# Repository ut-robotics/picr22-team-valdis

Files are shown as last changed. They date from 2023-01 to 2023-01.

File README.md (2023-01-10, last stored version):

# picr22-team-valdis

Pinout for STM32G441KBT6

PA0 - M1_PWM_A

PA1 - M2_PWM_A

PA2 - M3_PWM_A

PA3 - TRW_PWM

PA5 - M1_DIR_A

PA6 - M2_DIR_A

PA7 - M3_DIR_A

PA8 - M1_ENC_A

PA9 - M1_ENC_B

PA11 - USB_N

PA12 - USB_P

PA13 - SWDIO

PA14 - SWCLK

PF0-OSC_IN - LED

PG10-NRST - NRST

PB3 - SLEEP_n

PB4 - M2_ENC_A

PB5 - M2_ENC_B

PB6 - M3_ENC_B

PB7 - M3_ENC_A

Pins 1,17,15,16,32,14 are used for power. Rest of unmentioned pins were not used

For motor encoder inputs we used 2 channel inputs for each motor. Depicted as ENC_A and ENC_B connections. 
For output we used PWM and DIR (direction) where PWM transmitted speed and DIR chose which way the wheel spun.
The thrower was initially planned to use D-SHOT but due to time limitations we used simple PWM output.
Sleep_n is used to wake up motors.

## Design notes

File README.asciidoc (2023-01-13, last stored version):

# picr22-team-valdis Motor and Mainboard drivers

The purpose of this board is to control 3 motor drivers and 1 additional servo. This can be done with an external serial connection through USB. Additionally, the board also provides power for the 3 motor drivers (servo requires separate power source).

The main communication for each motor goes through STM32G441KBT6, which is separately programmable through J2 connector. Power delivery for this chip is supplied via USB 5V which is converted down to 3.3V through a voltage regulator (NCP164CSN330T1G). The USB connection also has protection provided by CM1223-02SO TVS diode package. An additional debug LED is also connected to indicate if signal is being outputted to motor drivers.

The motor driver side is powered by an external LiPo battery (in our case a 16.8V 4S) and is isolated from the MCU side. Before the signal reaches motor drivers, it goes through isolators (MAX14930DASE+) to ensure correct signal between two board power supplies. Batteries are connected via 4x4mm solder pads and go through a reverse voltage protector (BUK6Y10-30P) to protect components. For providing power to the isolators, voltage is dropped from 16V to 5V via voltage regulator (NCV8730ASN500T1G).

Motor drivers (PDRV8243HRXYQ1) receive 16.8V input for power. From the isolators, drivers receive a PWM, direction and sleep signal. PWM signal tells how fast the motors have to spin and direction signal indicates via boolean (0 or 1) which way the wheel spins. Sleep signal is basically there to wake up the motor drivers from standby state. For simplicity we connected DRVOFF to ground, which means that they will never be turned off while power is connected. Current for motor drivers are limited with 47K resistors through ITRIP pin and 2.2K resistors through IPROP pin. This sets ITRIP voltage to 2.31V and driver output current to around 3.2A. Motor driver power is also supplied through 4x4mm solder pads.

== Pinout for STM32G441KBT6

PA0 - M1_PWM_A (wheel PWM signal output)

PA1 - M2_PWM_A (wheel PWM signal output)

PA2 - M3_PWM_A	(wheel PWM signal output)

PA3 - TRW_PWM (thrower PWM signal)

PA5 - M1_DIR_A	(wheel direction output)

PA6 - M2_DIR_A (wheel direction output)

PA7 - M3_DIR_A (wheel direction output)

PA8 - M1_ENC_A (wheel encoder read)

PA9 - M1_ENC_B (wheel encoder read)

PA11 - USB_N (USB input data-)

PA12 - USB_P (USB input data+)

PA13 - SWDIO (Serial Wire Data I/O)

PA14 - SWCLK (Serial Wire Clock)

PF0-OSC_IN - LED (debug led for sending commands)

PG10-NRST - NRST (MCU reset)

PB3 - SLEEP_n (signal to wake up motor driver)

PB4 - M2_ENC_A (wheel encoder read)

PB5 - M2_ENC_B (wheel encoder read)

PB6 - M3_ENC_B (wheel encoder read)

PB7 - M3_ENC_A (wheel encoder read)

Pins 1,17,15,16,32,14 are used for power. Rest of unmentioned pins were not used.

== J2 Programmer

1 - 3.3V

2 - SWDIO

3 - GND

4 - SWCLK

5 - GND

6 - NC

7 - NC

8 - NC

9 - GND

10 - NRST

== J3 Motor 1

1 - GND

2 - 3.3V

3 - M1_ENC_A

4 - M1_ENC_B

== J4 Motor 2

1 - GND

2 - 3.3V

3 - M2_ENC_A

4 - M2_ENC_B

== J5 Motor 3

1 - GND

2 - 3.3V

3 - M3_ENC_A

4 - M3_ENC_B

== J6 Thrower 

1 - GND

2 - TRW_PWM

3 - NC

4 - NC

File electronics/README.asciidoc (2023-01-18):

# picr22-team-valdis Motor and Mainboard drivers

The purpose of this board is to control 3 motor drivers and 1 additional servo. This can be done with an external serial connection through USB. Additionally, the board also provides power for the 3 motor drivers (servo requires separate power source).

The main communication for each motor goes through STM32G441KBT6, which is separately programmable through J2 connector. Power delivery for this chip is supplied via USB 5V which is converted down to 3.3V through a voltage regulator (NCP164CSN330T1G). The USB connection also has protection provided by CM1223-02SO TVS diode package. An additional debug LED is also connected to indicate if signal is being outputted to motor drivers.

The motor driver side is powered by an external LiPo battery (in our case a 16.8V 4S) and is isolated from the MCU side. Before the signal reaches motor drivers, it goes through isolators (MAX14930DASE+) to ensure correct signal between two board power supplies. Batteries are connected via 4x4mm solder pads and go through a reverse voltage protector (BUK6Y10-30P) to protect components. For providing power to the isolators, voltage is dropped from 16V to 5V via voltage regulator (NCV8730ASN500T1G).

Motor drivers (PDRV8243HRXYQ1) receive 16.8V input for power. From the isolators, drivers receive a PWM, direction and sleep signal. PWM signal tells how fast the motors have to spin and direction signal indicates via boolean (0 or 1) which way the wheel spins. Sleep signal is basically there to wake up the motor drivers from standby state. For simplicity we connected DRVOFF to ground, which means that they will never be turned off while power is connected. Current for motor drivers are limited with 47K resistors through ITRIP pin and 2.2K resistors through IPROP pin. This sets ITRIP voltage to 2.31V and driver output current to around 3.2A. Motor driver power is also supplied through 4x4mm solder pads.

This board should be fine to operate any brushed 12V DC motor with a power output that exceeds 3.2A. For our general purpose we used 12V Pololu motors with a stall current of 5.5A at 12V. It is also important to use motors with encoders, otherwise the firmware won't work properly.

== Pinout for STM32G441KBT6

PA0 - M1_PWM_A (wheel PWM signal output)

PA1 - M2_PWM_A (wheel PWM signal output)

PA2 - M3_PWM_A	(wheel PWM signal output)

PA3 - TRW_PWM (thrower PWM signal)

PA5 - M1_DIR_A	(wheel direction output)

PA6 - M2_DIR_A (wheel direction output)

PA7 - M3_DIR_A (wheel direction output)

PA8 - M1_ENC_A (wheel encoder read)

PA9 - M1_ENC_B (wheel encoder read)

PA11 - USB_N (USB input data-)

PA12 - USB_P (USB input data+)

PA13 - SWDIO (Serial Wire Data I/O)

PA14 - SWCLK (Serial Wire Clock)

PF0-OSC_IN - LED (debug led for sending commands)

PG10-NRST - NRST (MCU reset)

PB3 - SLEEP_n (signal to wake up motor driver)

PB4 - M2_ENC_A (wheel encoder read)

PB5 - M2_ENC_B (wheel encoder read)

PB6 - M3_ENC_B (wheel encoder read)

PB7 - M3_ENC_A (wheel encoder read)

Pins 1,17,15,16,32,14 are used for power. Rest of unmentioned pins were not used.

== J2 Programmer

1 - 3.3V

2 - SWDIO

3 - GND

4 - SWCLK

5 - GND

6 - NC

7 - NC

8 - NC

9 - GND

10 - NRST

== J3 Motor 1

1 - GND

2 - 3.3V

3 - M1_ENC_A

4 - M1_ENC_B

== J4 Motor 2

1 - GND

2 - 3.3V

3 - M2_ENC_A

4 - M2_ENC_B

== J5 Motor 3

1 - GND

2 - 3.3V

3 - M3_ENC_A

4 - M3_ENC_B

== J6 Thrower 

1 - GND

2 - TRW_PWM

3 - NC

4 - NC

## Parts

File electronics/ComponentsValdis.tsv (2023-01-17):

Mainboard
Name | Description | Designator | Quantity | Mouser order code | Farnell order code | TME order code
STM32G441KBT6 | Microcontroller, 32-pin | U2 | 1 | 511-STM32G441KBT6 | 3132413 | -
10118193-0001LF | Micro USB socket | J1 | 1 | 649-10118193-0001LF | 2751675 | 10118193-0001LF/C
CM1223-02SO | TVS diodes 2-channel | U1 | 1 | 748-CM1223-02SO | 3607672 | CM1223-02SO
BUK6Y10-30PX | PFET SOT669 | Q1 | 1 | 771-BUK6Y10-30PX | 3438512 | BUK6Y10-30PX
MAX14930DASE+ | 4-channel isolator | U3,U4 | 2 | 700-MAX14930DASE+ | 3257451 | -
FTSH-105-01-L-DV-K | Programmer connector | J2 | 1 | 200-FTSH10501LDVK | 3550960 | -
NCV8730ASN500T1G | LDO 5V 150mA | U5 | 1 | 863-NCV8730ASN500T1G | 3463974 | -
NCP164CSN330T1G | LDO 3.3V 300mA | U6 | 1 | 863-NCP164CSN330T1G | 3367831 | NCP164CSN330T1G
Micro-MaTch 215079-4 | 4-pin connector | J3-J6 | 4 | 571-215079-4 | 1772996 | AMP-7-215079-4
Capacitor 100 nF | package 0603 | C2-C9 | 8 | 581-06035C104KAT2A | 1740614 | 0603B104J500CT
Capacitor 1 uF | package 0603 | C10-C13 | 4 | 581-06035C105KAT2A | 2118128 | 06033D105KAT2A
Capacitor 4.7 uF | package 0603 | C1 | 1 | 963-JMK107BB7475KA-T | 3013398 | GRJ188C70J475KE11D
Resistor 3K3 Ohm | package 0603 | R1-R5 | 5 | 603-RC0603FR-103K3L | 9238549 | WF06P-3K3-5%
LED | white 0603 | D1-D5 | 5 | 593-LSM0603443V | 1716769 | FYLS-0603UWC
Motor Driver
Name | Description | Designator | Quantity | Mouser order code | Farnell order code | TME order code
PDRV8243HRXYQ1 | Motor driver | U7,U8,U9 | 3 | 595-DRV8243HQRXYRQ1 | - | -
Capacitor 10 uF | package 0805 | C14-C17, C20-C23, C26-C29 | 12 | 581-08053D106KAT4A | 2346927 | C2012X5R1E106KAB
Capacitor 100 nF | package 0603 | C18,C19,C24,C25,C30,C31 | 6 | 581-06035C104KAT2A | 1740614 | 0603B104J500CT
Resistor 47K Ohm | package 0603 | R8,R14,R20 | 3 | 279-CRGCQ0603J47K | 2908376 | RC0603FR-0747K
Resistor 2K2 Ohm | package 0603 | R11,R17,R23 | 3 | 279-CRGCQ0603F2K2 | 9233423 | RC0603JR-072K2
Resistor 0 Ohm | package 0603 | R7,R9,R10,R13,R15,R16,R19,R21,R22 | 9 | 652-CR0603-J/-000ELF | 9233130 | RC0603JR-070R
LED | white 0603 | D6,D7,D8 | 3 | 593-LSM0603443V | 1716769 | FYLS-0603UWC
Resistor 3K3 Ohm | package 0603 | R6,R12,R18 | 3 | 603-RC0603FR-103K3L | 9238549 | WF06P-3K3-5%

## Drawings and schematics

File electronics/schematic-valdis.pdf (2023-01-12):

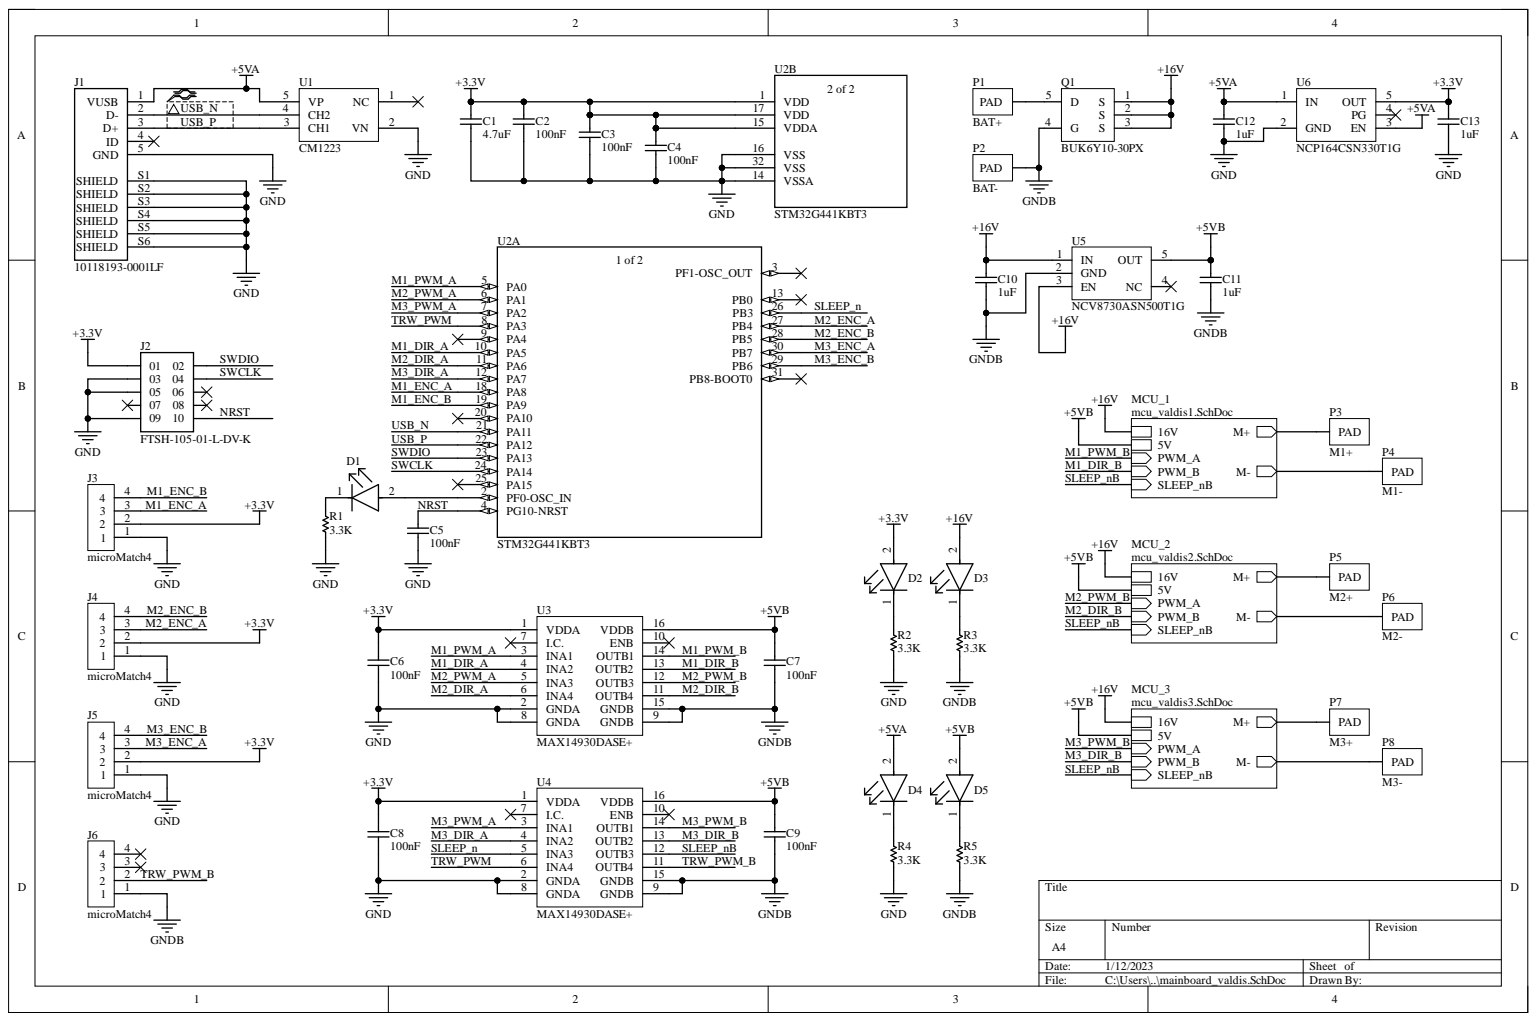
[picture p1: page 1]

1 | | 1 4 M1 _PWM_

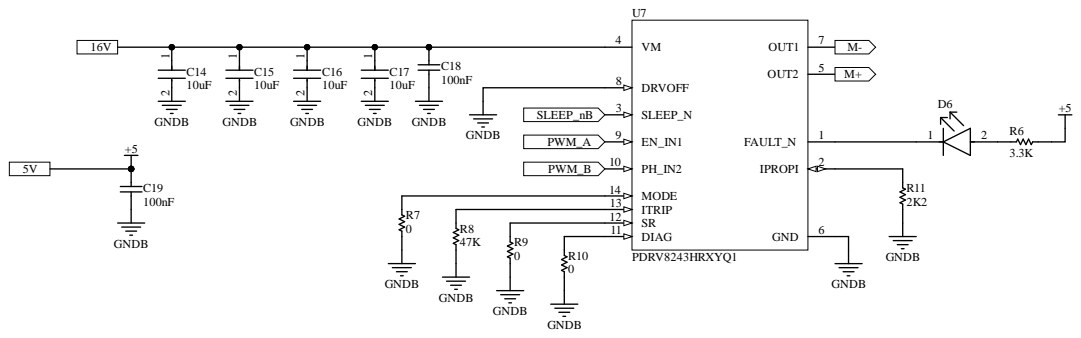
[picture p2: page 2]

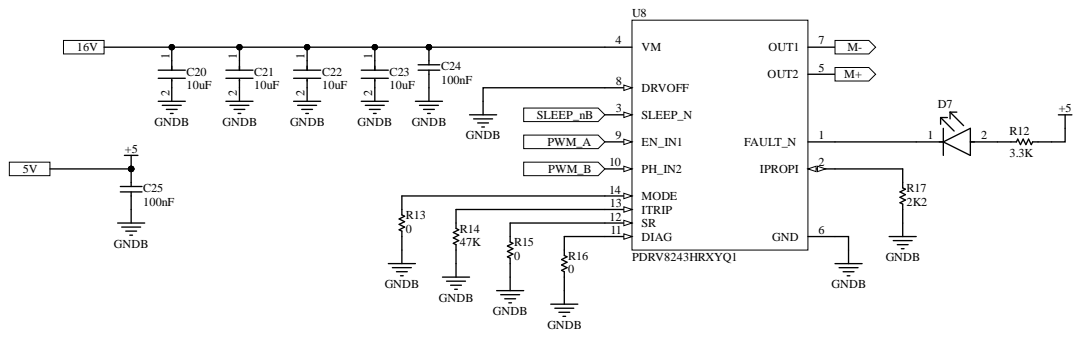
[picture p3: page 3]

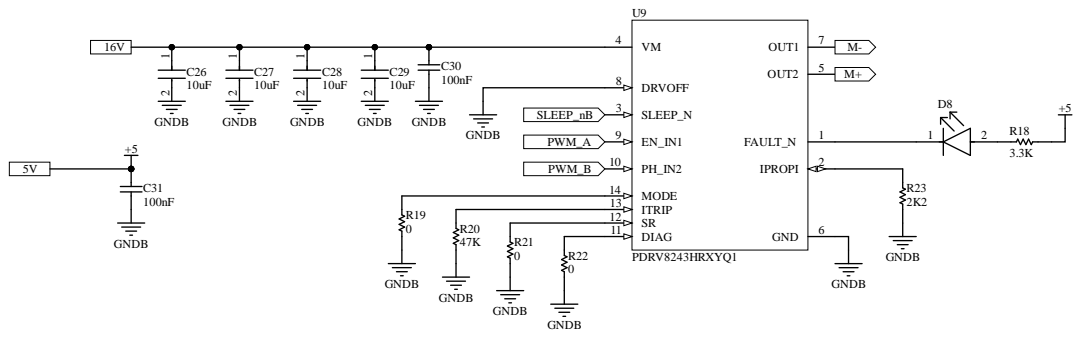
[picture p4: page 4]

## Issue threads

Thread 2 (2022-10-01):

[Mechanics] attach thrower assembly to chassis

Akustav, 2022-10-01:
I did not find a assembly file where the chassis and thrower are combined. Such a file allows to validate that the thrower will work in the chassis.

vircoh, 2022-10-02:
Asub Chassis kaustas: Robot throweritega

Closed 2022-10-05.

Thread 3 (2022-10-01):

[Mechanics] blue lines in sketches

Akustav, 2022-10-01:
Some sketches are left under defined. This can make it difficult to modify components later on and can create unpredictable situations when modifying things. This can be fixed by adding measurements to sketches until every line is black.

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

vircoh, 2022-10-02:
Võiks olla korras

Akustav, 2022-10-05:
Am I looking at the correct file? wall3 v15 has a lot of blue:
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

Ramp3 v4 has one hole underdefined:
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

Closed 2022-11-05.

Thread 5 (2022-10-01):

[Mechanics] mounting hole size too large

Akustav, 2022-10-01:
Mounting holes for the thrower should have 2.5mm holes that can be threaded and used with M3 bolts.
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

vircoh, 2022-10-02:
done - 2.5mm

Closed 2022-10-05.

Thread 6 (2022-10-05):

[Mechanics] thrower motor seems to be too low

Akustav, 2022-10-05:
The motor is currently too low. It should compress the ball a few mm, like 2-3 mm. Currently it is 7.8mm

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

Also add the motor to the assembly. It does not need to be too detailed, a cylinder with mounting holes and a rectangle representing the power cables is enough.

Closed 2022-11-05.

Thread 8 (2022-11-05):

[Mechanics] errors is assembly

Akustav, 2022-11-05:
Thr omniwheel assembly seems to have warnings:

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

vinku34, 2022-11-05:
Fixed errors in timeline

Closed 2022-11-26.

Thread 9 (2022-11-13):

MCU pin assignment

ReikoR, 2022-11-13:
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

USB and programmer pins must be connected to pins PA11 to PA14:
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

Most of the other pins also would not work.

Try to use STM32CubeIDE for creating the pin assignment.

Some more information on how to configure timers in STM32CubeIDE is on the firmware page:
https://ut-robotics.github.io/picr22-home/basketball_robot_guide/electronics/firmware.html

Please ask if it's not clear how to do the timer configuration and pin assignment.

ReikoR, 2022-11-16:
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

Pin assignment is ok, but why are you naming all the signals `ENC`?

Something like this would be more understandable:
* `M1_PWM` - Motor 1 PWM
* `M1_DIR` - Motor 1 direction
* `M1_ENC_A` - Motor 1 encoder A
* `M1_ENC_A` - Motor 2 encoder B
* `TRW_PWM` - Thrower PWM

ReikoR, 2022-11-18:
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

Each driver has one PWM and one direction input.

Connections should look like this:
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

ReikoR, 2022-11-19:
It would make the firmware a bit simpler if all ENC_A signals where connected to timer channel 1.

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

Closed 2022-11-20.

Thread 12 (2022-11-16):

+3.3V power port not connected

ReikoR, 2022-11-16:
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

ReikoR, 2022-11-18:
Now it's missing:
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

Closed 2022-11-19.

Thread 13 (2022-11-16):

Thrower PWM signal should go through isolator

ReikoR, 2022-11-16:
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

`DRVOFF` can be removed from MCU and connected to `GNDB` on motor drivers. Then an additional isolator is not needed.

I don't think there is any need to turn off drivers from MCU.

Closed 2022-11-18.

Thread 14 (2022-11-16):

Don't use metric grid on the schematic

ReikoR, 2022-11-16:
Industry standard unfortunately is 100 mil grid. All the symbols are designed for it. Using different grid can cause issues with things not aligning with each other.

On the PCB it's better to use metric grid.

Closed 2022-11-18.

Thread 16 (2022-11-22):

Incorrect MicroMatch footprint

ReikoR, 2022-11-22:
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

From the [drawing](https://www.te.com/commerce/DocumentDelivery/DDEController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):
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

Polarization hole is too small:
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

Also pin numbering should start from the polarization hole side.

You can use this library:
https://github.com/ReikoR/altium-custom-libraries/tree/master/connectors_micromatch

Or some other library, if you find a correct one.

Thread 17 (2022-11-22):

NCV8730ASN500T1G footprint incorrect

ReikoR, 2022-11-22:
Pin pitch on the footprint is 0.65 mm:
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

Correct from [datasheet ](https://www.onsemi.com/pdf/datasheet/ncv8730-d.pdf) is 0.95 mm:
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

ReikoR, 2022-12-02:
Still incorrect:
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

Closed 2022-12-04.

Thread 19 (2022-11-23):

Route USB data signals as differential pair

ReikoR, 2022-11-23:
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

For more info:
https://github.com/ut-robotics/picr22-team-gibibot/issues/32

But use JLC7628 stackup instead of JLC3313 as it is cheaper.

USB differential pair trace width and spacing is different for JLC7628 stackup.

For example 8 mil (about 0.2 mm) trace space and 10.28 mil (about 0.26 mm) trace width would work:
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

ReikoR, 2022-11-27:
1. JLC7628 stackup not being used:
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

2. Avoid creating stubs. Stubs create reflections.
\
Current layout:
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
\
Proposed layout:
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

ReikoR, 2022-12-02:
JLC7628 stackup still not being used. Track width needs to be changed.

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

Closed 2022-12-04.

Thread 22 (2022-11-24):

[Mechanics] CAM issues

maidlam, 2022-11-24:
Arrange:
Set "Object Spacing" to 7 mm. The space between the parts should be greater than 6 mm, because the tool is 3 mm in diameter, the toolpath will want to preserve the stock between parts until the end, causing longer milling time.

2D Pocket:

- Change Stock to Leave > Axial Stock to Leave to 0
- Disable Lead-In and Lead-Out
- Change Ramp > Ramp type to Plunge

2D Contour1 (hole for the motor shaft)

- Enable tabs, set "Tab height" to 0,3 mm, set "Tab distance" so that it generates two tabs for the inner piece
- Enable Multiple Depths and set the "Maximum Roughing Stepdown" to 1 mm
- Enable Stock to Leave, set Radial Stock to leave to -0,05 - this will let the shaft brim fit more easily, by making the hole a little bit bigger.
- Disable Lead-In and Lead-Out

2D Contour2 (outside contours)

- Change "Tab height" to 0,3 mm
- Enable Multiple Depths and set the "Maximum Roughing Stepdown" to 1 mm
- Disable Lead-In and Lead-Out

Closed 2022-11-27.

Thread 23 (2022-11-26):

Not that many mounting points needed

Akustav, 2022-11-26:
I suggest not to use these mounting holes because they add more complexity for barely any benefit. same for the bottom holes:

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

vinku34, 2022-11-26:
Removed ramp mounting holes on top and bottom plate

Closed 2022-12-04.

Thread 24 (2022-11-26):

Consider using mountable XT-60 sockets

Akustav, 2022-11-26:
Maybe the use of a mountable XT-60 socket like this is good to power the robot.
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

vinku34, 2022-11-26:
do we have this kind of mountable connector or would I have to make a holder to make it mountable?

Akustav, 2022-12-04:
They are available in the lab

vinku34, 2022-12-05:
I made a variant with these mountable sockets. The current issue would be on the side with the NUC power cable. Right now I can move it closer to the edge a bit but im not 100% sure if it will clear the power cable or not.
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

Also the holes in the rear acted as a place to shove the battery voltage displays. I have an Idea to mount them here with 3D printed boxes and screw in from the inside with the same flush fit as most of the bolts I have. with little indents for nuts so that I dont have to thread plastic
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

Akustav, 2022-12-07:
Seems reasonable. Also FYI, the XT-60 sockets themselves have threaded inserts, so you just need a 3mm hole to mount them. Your current holes are 2.5mm

Closed 2022-12-14.

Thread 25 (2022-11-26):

How do sidewalls mount

Akustav, 2022-11-26:
What fastening stiles is used for the sidewalls? Currently they look bottom mounted. What holds them in place?

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

vinku34, 2022-11-26:
Bolts go through from the bottom and thread into a nyloc nut from the top.

Akustav, 2022-12-04:
Hm okay. I guess

Closed 2022-12-04.

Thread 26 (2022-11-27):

Add grounds to both internal layers

ReikoR, 2022-11-27:
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

Add `GND` net polygon on both internal layers on the MCU side and `GND_M` net polygon on both layers on the motor drivers side.

Grounds are reference planes for signal and power connections on outer layers and having reference plane close to signals improves signal integrity.

ReikoR, 2022-12-02:
There are duplicate polygons. I moved them for the picture.
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

Closed 2022-12-04.

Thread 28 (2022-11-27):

Fix DRC errors

ReikoR, 2022-11-27:
There are unrouted nets and other problems.

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

ReikoR, 2022-12-02:
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

Some of the solder mask sliver errors can be fixed by adding back general Solder Mask Expansion rule and setting expansion to 0.05mm (JLCPCB minimum).
From https://jlcpcb.com/capabilities/Capabilities
> Solder mask opening/ expansion 0.05mm

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

Via Solder Mask Expansion rule should be the first one. Rule order can be changed with _Priorities..._ button.

Correct minimum solder mask sliver should be 0.254 mm, which will cause more errors.

From https://jlcpcb.com/capabilities/Capabilities
> Solder bridge: 0.2mm(green), 0.254mm(other colors)

PCBs will be black.

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

It should be ok to ignore solder mask sliver errors that can't be fixed.

Closed 2022-12-04.

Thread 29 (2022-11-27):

Avoid routing over gaps

ReikoR, 2022-11-27:
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

If If there is not a solid ground on the adjacent layer, then the return current has to flow in a bigger loop, which causes more noise.

Closed 2022-12-02.

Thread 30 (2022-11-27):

Place decoupling capacitors on the same layer as the components

ReikoR, 2022-11-27:
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

Placing capacitors on the same layer close to the power pins makes the connection shorter, which reduces inductance.

Closed 2022-12-02.

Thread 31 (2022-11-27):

Use wider tracks or polygons and multiple vias for higher currents

ReikoR, 2022-11-27:
1. High current connections are quite narrow.
\
Current layout:
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
\
0.254mm wide copper can carry about 1.7 A of current at 20 degrees temperature rise:
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
\
For 3 A, the temperature needs to rise by 73 degrees.
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

2. Multiple smaller vias instead of fewer larger vias is usually better as smaller vias can carry more current per area.
\
Current layout:
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
\
0.2/0.45mm via:
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
\
0.6/1mm vias:
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

More copper and better connection to it also helps with thermal performance.

ReikoR, 2022-12-02:
1. More vias should be added to +16V from MOSFET.
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

2. Motor driver capacitors would be more effective if they were closer to motor drivers. Smallest (100nF) capacitor should be the closest. Shorter connections have lower inductance.
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

3. There are 2 overlapping +16V polygons.
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

4. Improve `SLEEP_nB` routing so that it does not cut into +16V polygon.
\
Current layout:
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
\
Proposed layout (routed mostly on top layer):
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

Closed 2022-12-05.

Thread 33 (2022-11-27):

Prefer tented vias

ReikoR, 2022-11-27:
Untented vias can cause shorts or soldering problems in some cases.

Simplest way to use tented vias is to create new Solder Mask Expansion rule:
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

Closed 2022-12-02.

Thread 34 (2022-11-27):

Incorrect DRV8243 configuration resistor

ReikoR, 2022-11-27:
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

4.7k is not a correct value for a configuration resistor.

From [datasheet](https://ut-robotics.github.io/picr22-home/basketball_robot_guide/electronics/drv8243-q1_datasheet_2021-08.pdf):
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

Closed 2022-12-02.

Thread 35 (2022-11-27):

Incorrect motor driver capacitor values

ReikoR, 2022-11-27:
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

100uF is too big of a capacitance for 0805 25V+ capacitors.

Closed 2022-12-02.

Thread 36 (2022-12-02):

Avoid routing ground

ReikoR, 2022-12-02:
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

Place ground vias close to the component ground pins to connect them to internal ground layers.

ReikoR, 2022-12-04:
One example:

Current layout:
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

Proposed layout:
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

ReikoR, 2022-12-04:
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

Closed 2022-12-04.

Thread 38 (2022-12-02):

Mounting hole too close to components

ReikoR, 2022-12-02:
I added a cylinder with a diameter of 5.5 mm (same as M3 bolt head) on the PCB.

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

Other mounting hole is very close to the PCB edge:
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

ReikoR, 2022-12-04:
Other mounting hole might be too close to the motor output pads or might damage the solder mask and short the copper below.

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

vinku34, 2022-12-04:
Can I just keep the one mounting hole then? It won't be supporting much weight anyways.

ReikoR, 2022-12-04:
It would be better to have at least 2 mounting holes to prevent the PCB from rotating.

There is room near the original location, it was just too close to the edge before. Silkscreen text needs to be moved. Silkscreen text can also be smaller if there is not enough room.

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

Closed 2022-12-04.

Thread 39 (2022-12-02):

Add numbers to encoder connectors and motor drivers

ReikoR, 2022-12-02:
It would be easier to connect the wires if the encoder connectors and motor drivers were numbered on the silkscreen.

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

vinku34, 2022-12-02:
Connector labels are located on the other side of the pcb with rectangles around them

ReikoR, 2022-12-02:
I meant adding numbers like 1, 2, 3 for both encoder connectors and motor drivers so it would be easier to match them while connecting the wires.

ReikoR, 2022-12-04:
For example:
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

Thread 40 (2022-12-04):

Silk to solder mask clearance errors

ReikoR, 2022-12-04:
It's not correct to set _Silk To Solder Mask Clearance_ rule to 0 mm:
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

From [JLCPCB capabilities](https://jlcpcb.com/capabilities/Capabilities):
> Pad To Silkscreen 0.15mm

Errors:
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

Closed 2022-12-04.

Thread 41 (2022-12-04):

Avoid routing tracks close to each other

ReikoR, 2022-12-04:
Having tracks close to each other causes more crosstalk.

Current layout:
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

Proposed layout:
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

Closed 2022-12-04.

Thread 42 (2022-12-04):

Create Gerber X2 files

ReikoR, 2022-12-04:
Create Gerber X2 layer and drill files (*.gbr) and commit them to repository for ordering the manufacturing.

Settings (file names will be different):
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

Closed 2022-12-05.

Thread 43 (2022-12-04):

Reference designators not next to the components

ReikoR, 2022-12-04:
Reference designators are on the bottom layer, but components are on the top. They should be next to the components.

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

Silkscreen text can be smaller if it does not fit.

JLCBPCB minimum recommended:
Minimum Line Width 6 mil (0.153mm)
Minimum text height 40 mil (1.0mm)
https://jlcpcb.com/capabilities/Capabilities

0.8 mm height has also worked before.

Right clicking on one of the reference designators allows to open _Find Similar Objects..._.
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

This allows to select all of them and then change all of them from properties panel.

Closed 2022-12-05.

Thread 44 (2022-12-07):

CAM - Increase Frame Width in Arrange

maidlam, 2022-12-07:
Increase the Frame Width in Arrange so there's some leeway when milling the parts.

7 mm should be okay for the Frame Width.

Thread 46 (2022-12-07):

CAM - Operations issues:

maidlam, 2022-12-07:
Drilling:

- Heights > Top Height - Change From to "Stock Top"

2D Pocket:

- Passes > Stock to Leave - Change Axial Stock to Leave to 0

2D Contour (inner cuts):

- Geometry > Tabs - Change Tab Positioning to "Number of Tabs", Tabs per Contour to 0, add Manual tabs to camera mount, switches, pc adapter socker, motor mount, etc. where the holes have a width greater than 6 mm. For bigger holes add more tabs are suggested, but at least 2 tabs per contour.
This will avoid making tabs in the slots that are 4,8 mm wide.

2D Contour (outer cuts):

- Passes - Disable Stock to Leave

Closed 2022-12-14.

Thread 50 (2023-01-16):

Electronics documentation

ReikoR, 2023-01-16:
1. _"stall current of 5.5A @ 12W"_
\
Stall current is 5.5A at 12V.

2. _"This board should be fine to operate any 12V motor"_
\
Specify which type of motors. AC, DC? Brushed, brushless?

ReikoR, 2023-01-18:
1. _"5.5A at 12W"_
\
12V (volts), not 12W (Watts)

Closed 2023-01-18.

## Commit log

2022-11-13 added mainboard and mcu schematic files
    [ValdisMCU.SchDoc, ValdisMainboardSchematic.SchDoc]
2022-11-13 added more files
    [NCP164CSN330T1G.PcbLib, NCP164CSN330T1G.SchLib, PDRV8243HRXYQ1.PcbLib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]
2022-11-14 fixed schematic and added PrjPcb file
    [STM32G441KBT3.PcbLib, STM32G441KBT3.SchLib, ValdisMCU.SchDoc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]
2022-11-14 added missing files
    [ValdisMCU.SchDoc, ValdisMainboardSchematic.SchDoc]
2022-11-18 fixed schematic and added all needed footprints for pcb
    [10118193-0001LF.PcbLib, 10118193-0001LF.SchLib, 215079-4.PcbLib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]
2022-11-19 fixed schematic errors, added gitignore for certain folders
    [10118193-0001LF.PcbLib, 10118193-0001LF.SchLib, 215079-4.PcbLib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]
2022-11-19 removed unnecessary folders
    [ValdisPCB.PcbDoc]
2022-11-20 fixed netlabel and thrower ground connection
    [ValdisPCB.PcbDoc, mainboard_valdis.SchDoc]
2022-11-21 PCB layout ready for revision
2022-11-22 new board with updated footprints
    [PCB2.PcbDoc, mainboard_valdis.SchDoc, mcu_valdis.SchDoc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]
2022-11-22 fixed issues with footprints and pcb
    [10118193-0001LF.PcbLib, 10118193-0001LF.SchLib, 215079-4.PcbLib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]
2022-11-27 pcb revision
    [ValdisPCB.PcbDoc, mainboard_valdis.SchDoc]
2022-12-01 new pcb with fixed issues
    [PCB1.PcbDoc, ValdisPCB.PcbDoc, mcu_valdis1.SchDoc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]
2022-12-04 pcb fixes
    [PCB1.PcbDoc]
2022-12-04 added motor capacitor gndb and fixed ground routing
    [PCB1.PcbDoc]
2022-12-04 fixed ground issues
    [PCB1.PcbDoc]
2022-12-04 added gerber files
    [10118193-0001LF.PcbLib, 10118193-0001LF.SchLib, 215079-4.PcbLib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]
2022-12-04 made symbols smaller
    [PCB1.PcbDoc, picr22-valdis.PrjPcb]
2022-12-04 new gerber files with smaller top overlay
    [PCB1.PcbDoc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]
2022-12-04 quick fix
    [PCB1.PcbDoc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]
2022-12-22 added firmware files
    [PCB1.PcbDoc, picr22-valdis.PrjPcb]
2023-01-10 added ComponentsValdis.tsv file
    [ComponentsValdis.tsv]
2023-01-10 added components file
    [ComponentsValdis.tsv]
2023-01-15 refactor 2
    [ComponentsValdis.tsv]
